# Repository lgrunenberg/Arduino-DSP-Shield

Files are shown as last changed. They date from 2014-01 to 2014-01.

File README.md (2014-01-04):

Arduino-DSP-Shield
==================

Eagle files for a DSP Shield to be used with Arduino Duemilanove and others.

It utilizes the Analog Devices ADAU1701 DSP IC. It also has solder pads for an EEPROM that can be used to store configurations and allow the ADAU to boot automatically when not connected to an Arduino.

Inputs and outputs are brought out to a pin header as I thought it would be more convenient than having TRS jacks directly on the board.

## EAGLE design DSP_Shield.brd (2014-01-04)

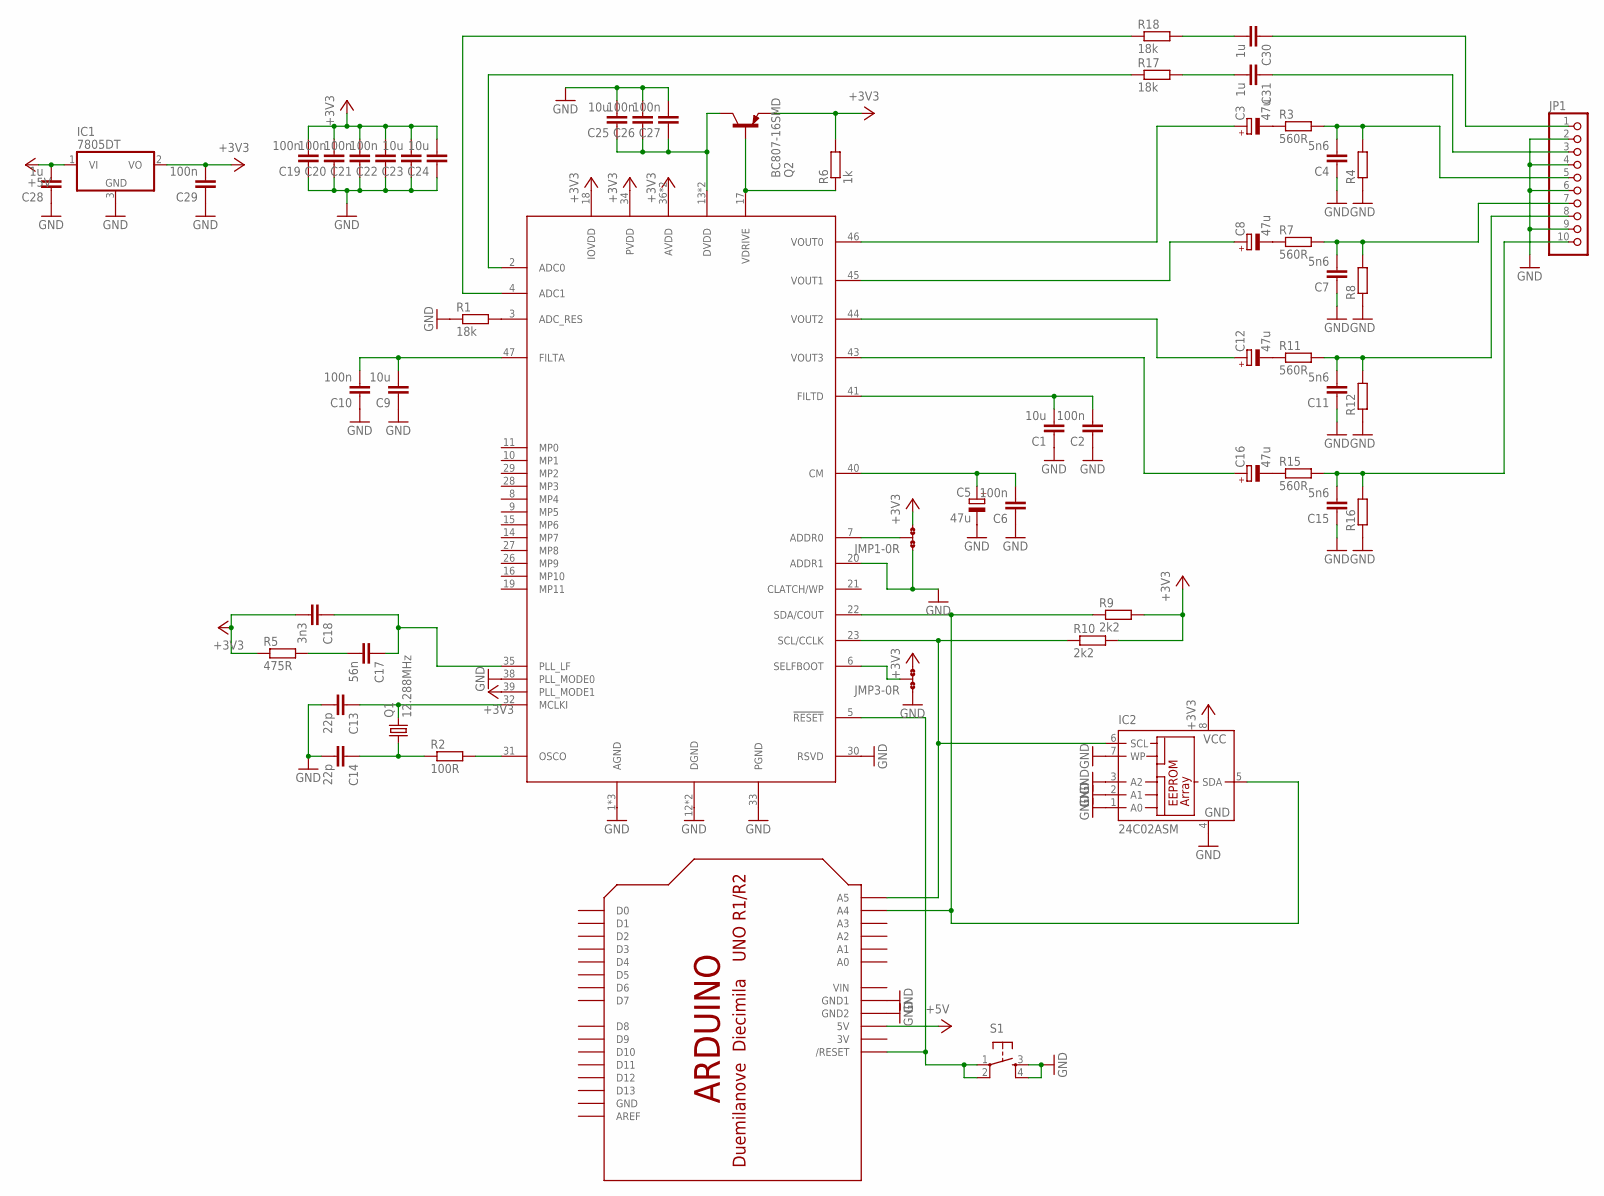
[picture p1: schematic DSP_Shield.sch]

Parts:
C1, C9, C23, C24, C25: 10u; C0805
C2, C6, C10, C19, C20, C21, C22, C26, C27, C29: 100n; C0805
C3, C8, C12, C16: 47u; PANASONIC_D
C4, C7, C11, C15: 5n6; C0805
C5: 47u; PANASONIC_B
C13, C14: 22p; C0805
C17: 56n; C0805
C18: 3n3; C0805
C28, C30, C31: 1u; C0805
IC1: 7805DT; TO252
IC2: 24C02ASM; SO-08M
JMP1, JMP3: 0R-JUMPA; A0R-JMP
JP1: PINHD-1X10/90; 1X10/90
Q1: 12.288MHz; HC49UP
Q2: BC807-16SMD; SOT23-BEC
R1, R17, R18: 18k; R0805
R2: 100R; R0805
R3, R7, R11, R15: 560R; R0805
R4, R8, R12, R16: R-EU_R0805; R0805
R5: 475R; R0805
R6: 1k; R0805
R9, R10: 2k2; R0805
S1: TAC_SWITCHSMD; TACTILE_SWITCH_SMD
U$1: ARDUINO-NODIM
U$2: ADAU1701; TQFP48

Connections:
3V: U$1.3V
+3V3: C18.2, C19.2, C20.2, C21.2, C22.2, C23.2, C24.2, C29.2, IC1.2 (VO), IC2.8 (VCC), JMP1.3, JMP3.3, Q2.E, R5.1, R6.2, R9.2, R10.2, U$2.18 (IOVDD), U$2.34 (PVDD), U$2.36 (AVDD), U$2.39 (PLL_MODE1), U$2.48 (AVDD)
+5V: C28.2, IC1.1 (VI), U$1.5V
GND: C1.1, C2.1, C4.1, C5.-, C6.1, C7.1, C9.1, C10.1, C11.1, C13.2, C14.2, C15.1, C19.1, C20.1, C21.1, C22.1, C23.1, C24.1, C25.2, C26.2, C27.2, C28.1, C29.1, IC1.3 (GND), IC2.1 (A0), IC2.2 (A1), IC2.3 (A2), IC2.4 (GND), IC2.7 (WP), JMP1.1, JMP3.1, JP1.2, JP1.4, JP1.6, JP1.9, R1.1, R4.1, R8.1, R12.1, R16.1, S1.3, S1.4, U$1.GND, U$1.GND1, U$1.GND2, U$2.1 (AGND), U$2.12 (DGND), U$2.20 (ADDR1), U$2.25 (DGND), U$2.30 (RSVD), U$2.33 (PGND), U$2.37 (AGND), U$2.38 (PLL_MODE0), U$2.42 (AGND)
unnamed: R2.2, U$2.31 (OSCO)
unnamed: R1.2, U$2.3 (ADC_RES)
unnamed: C1.2, C2.2, U$2.41 (FILTD)
unnamed: C3.-, R3.1
unnamed: C4.2, JP1.5, R3.2, R4.2
unnamed: C14.1, Q1.1, R2.1
unnamed: C5.+, C6.2, U$2.40 (CM)
unnamed: C9.2, C10.2, U$2.47 (FILTA)
unnamed: C8.-, R7.1
unnamed: C7.2, JP1.7, R7.2, R8.2
unnamed: C13.1, Q1.2, U$2.32 (MCLKI)
unnamed: R18.1, U$2.4 (ADC1)
unnamed: C17.2, R5.2
unnamed: C12.-, R11.1
unnamed: C11.2, JP1.8, R11.2, R12.2
unnamed: C16.+, U$2.43 (VOUT3)
unnamed: C17.1, C18.1, U$2.35 (PLL_LF)
unnamed: JMP1.2, U$2.7 (ADDR0)
unnamed: C16.-, R15.1
unnamed: C15.2, JP1.10, R15.2, R16.2
unnamed: IC2.6 (SCL), R10.1, U$1.A5, U$2.23 (SCL/CCLK)
unnamed: IC2.5 (SDA), R9.1, U$1.A4, U$2.22 (SDA/COUT)
unnamed: C12.+, U$2.44 (VOUT2)
unnamed: C8.+, U$2.45 (VOUT1)
unnamed: C3.+, U$2.46 (VOUT0)
unnamed: S1.1, S1.2, U$1.RESET (/RESET), U$2.5 (!RESET)
unnamed: C31.1, JP1.3
unnamed: C30.1, JP1.1
unnamed: R17.1, U$2.2 (ADC0)
unnamed: C31.2, R17.2
unnamed: C25.1, C26.1, C27.1, Q2.C, U$2.13 (DVDD), U$2.24 (DVDD)
unnamed: Q2.B, R6.1, U$2.17 (VDRIVE)
unnamed: C30.2, R18.2
unnamed: JMP3.2, U$2.6 (SELFBOOT)
VIN: U$1.VIN

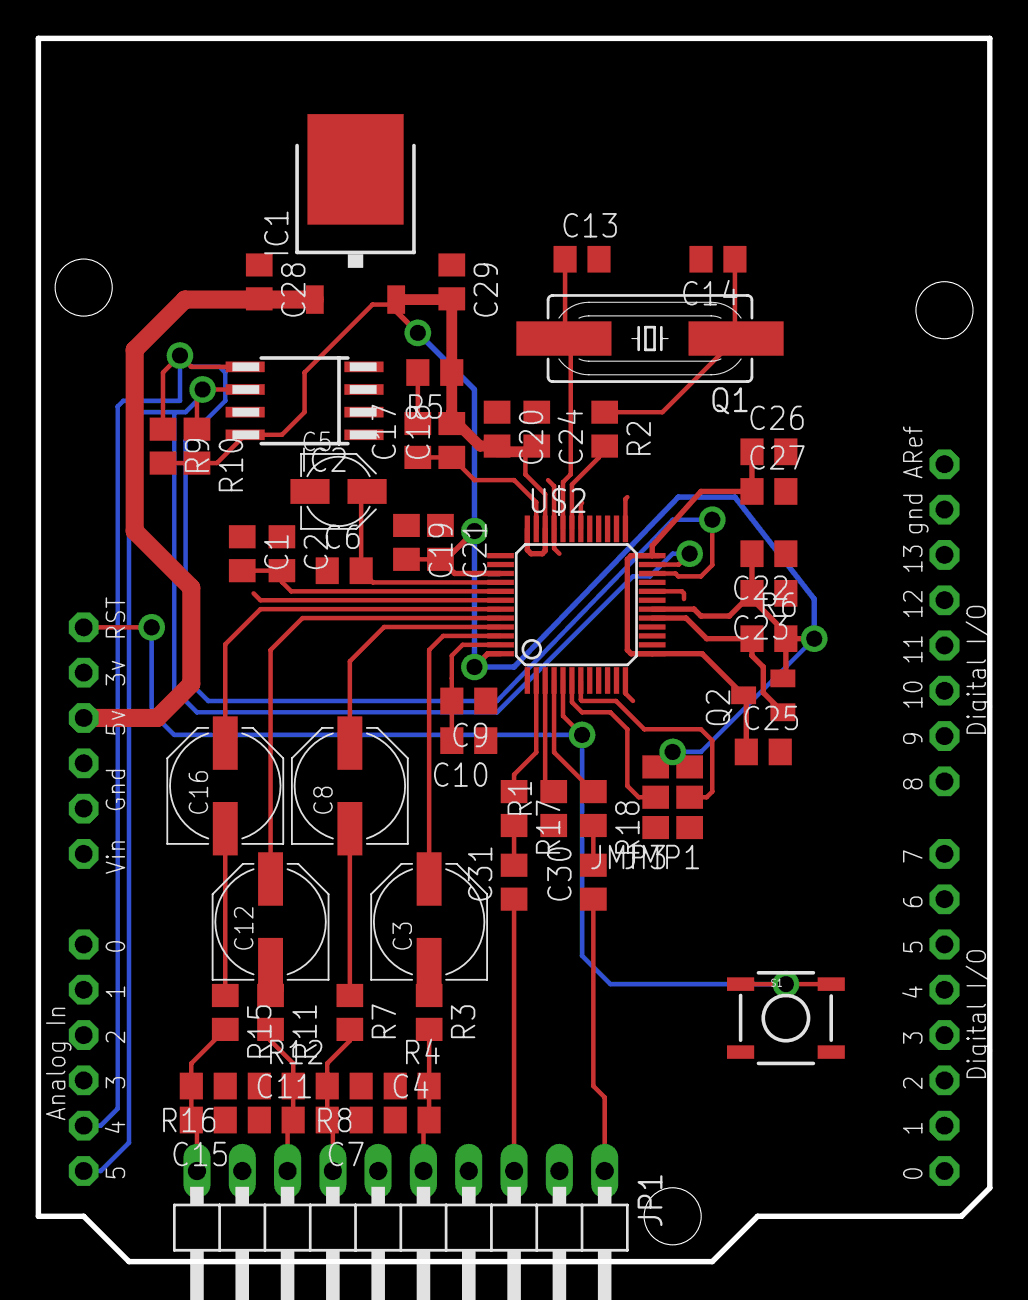
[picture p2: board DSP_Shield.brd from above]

Board: 2 copper layers, 53.3 x 68.6 mm, 57 parts (0 on the bottom side), 37 nets.
